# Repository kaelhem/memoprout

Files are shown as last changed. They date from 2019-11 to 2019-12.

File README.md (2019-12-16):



# MemoProut Pad
An open-source Arduino audio game (in french only until now...).

In this repository you will find Arduino source code, sounds and everything necessary to make your own MemoProut Pad!

## Contributing

Contributions in any form are welcome! If you find a bug, please [file an issue.](https://github.com/kaelhem/memoprout/issues)

## License

This project is licensed under the MIT license. See the [LICENSE file](./LICENSE) for more details.

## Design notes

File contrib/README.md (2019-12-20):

# MemoProut Pad - contributions

Vous avez une super idée pour un nouveau mode de jeu  à mettre sur votre MemoProut Pad ? Ce guide vous donne la marche à suivre.

##  Créer de nouveaux sons

Les sons du MemoProut Pad sont encodés en PCM (8bits), et enregistrés dans des fichiers _.wav_.

La méthode la plus simple est d'utiliser [Audacity](https://www.audacityteam.org/) qui est gratuit, open-source et multi-plateforme.

Il y plusieurs étapes à effectuer avec Audacity afin d'encoder chaque son dans un format valide pour votre MemoProut Pad.

1. Ouvrez votre fichier sonore avec Audacity.

2. Sélectionnez tout (dans le menu, cliquez sur _Sélectionner/Tout_)

3. Si le son est en stéréo, le passer en mono (dans le menu, cliquez sur _Pistes/Mix/Mix stéréo vers mono_)

4. Normaliser le volume (dans le menu, cliquez sur _Effets/Normaliser..._) avec les paramètres par défaut (-1.0 dB d'amplitude de crête)

5. Changer la fréquence pour 11025 Hz (sélectionnez 11025 dans la liste déroulante _"Taux du projet"_ en bas à gauche)

6. Mixer le rendu (dans le menu, cliquez sur _Pistes/Mix/Mixage et rendu_)

7. Exporter le son au bon format (dans le menu, cliquez sur _Fichier/Exporter/Exporter l'audio..._) puis sélectionnez ces options :

   + **Type de filtre** : _Autres formats non-compressés_
   + **Entête** : _WAV (Microsoft)_
   + **Encodage** : _Unsigned 8-bits PCM_

## Créer un nouveau mode de jeu

Il existe 2 styles de jeux différents : _"prose"_ où les sons joués forment des phrases, et _"simple"_ où les sons joués s'enchainent sans ordre particulier.

#### Style _prose_

Pour créér un mode de jeu basé sur des phrases, il faut préparer un dossier avec un nom court (6 lettres max.) en majuscules, contenant :

+ 8 sons de _sujets_ (ex. "Donald Trump", "La mouche qui pète", ...) nommés SUBJECT1.wav, SUBJECT2.wav, ... etc jusque SUBJECT8.wav (les majuscules sont importantes).
+ 8 sons d'actions (ex. "se prend pour", "a mangé", ...) nommés VERB1.wav, VERB2.wav, ...etc.
+ 8 sons de _complément_ (ex. "une banane", "une crotte de chien", ...) nommés COMP1.wav, COMP2.wav, ...etc.
+ 4 sons de liaison (ex. "et après", "ensuite", ...) nommés INTER1.wav, INTER2.wav, ...etc.
+ 1 son pour le nom du mode de jeu nommé GAME.wav
+ 1 son pour le _game-over_ nommé LOOSE.wav

#### Style _simple_

Pour créér un mode de jeu basé sur des sons simples, il faut préparer un dossier avec un nom court (6 lettres max.) en majuscules, contenant :

+ 28 sons nommés M1.wav, M2.wav, ...etc. jusque M28.wav (les majuscules sont importantes).

+ 1 son pour le nom du mode de jeu nommé GAME.wav
+ 1 son pour le _game-over_ nommé LOOSE.wav

## Ajouter un mode de jeu sur mon MemoProut Pad

Afin que votre nouveau mode de jeu puisse fonctionner sur votre MemoProut Pad, il faut :

+ copier le dossier précedemment créé à la racine de la carte SD.

+ dans le dossier _GAMES_ de la carte SD, dupliquer le fichier BASIC.PRT (pour le style _"prose"_) ou MUSIC.PRT (pour le style _"simple"_), et le renommer comme le dossier précédemment créé en conservant l'extension _.PRT_. Par exemple si votre dossier se nomme _"MACHIN"_, ce fichier devra être nommé _"MACHIN.PRT"_.

+ à l'aide d'un éditeur de texte, ouvrir le fichier GAMES.PRT se trouvant à la racine de la carte SD et ajouter une ligne contenant le nom de dossier, un espace et un 1 (pour le style _"prose"_) ou un 2 (pour le style _"simple"_).

  >  Par exemple, pour un style de jeu _"prose"_ et un dossier nommé _"MACHIN"_, ajouter cette ligne :

  ```
  MACHIN 1
  ```

  >  Pour un style de jeu _"simple"_ et un dossier nommé _"MACHIN"_, ajouter cette ligne :

  ```
  MACHIN 2
  ```

Et voilà ! Vous pouvez maintenant profiter de votre nouveau mode de jeu personnalisé.

## Comment partager mon mode jeu ?

Pour partager un nouveau mode de jeu, vous pouvez ouvrir une _pull-request_ sur le GitHub du projet en plaçant votre mode de jeu dans le dossier _"contrib"_ de la branche _master_.

Si vous ne savez pas comment faire, le plus simple est encore de m'envoyer un mail avec les sons en pièce jointe sur memoproutpad@gmail.com, et je m'occuperai du reste.

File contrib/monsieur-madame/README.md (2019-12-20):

# MemoProut Pad - monsieur / madame

## C'est quoi ?

Un mode de jeu supplémentaire pour adultes.

## Comment on l'installe ?

1. [Télécharger les sources](https://github.com/kaelhem/memoprout/archive/master.zip)
2. Dé-zipper l'archive et aller dans le dossier _master/contrib/monsieur-madame_
3. Copier le dossier _MRMME_ à la racine de la carte SD.
4. Copier le fichier _MRMME.PRT_ dans le dossier _GAMES_ de la carte SD.
5. Avec un éditeur de texte, éditer le fichier _GAMES.PRT_ de la carte SD pour ajouter cette ligne :

```
MRMME 2
```

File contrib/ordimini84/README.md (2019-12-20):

# MemoProut Pad - ordimini 1984

Nostalgie, nostalgie...

## C'est quoi ?

Un mode de jeu supplémentaire basé sur les sons du memo de l'Ordimini !

> Ces sons ont été récupérés via l'excellent émulateur : [ordimini.net](http://www.ordimini.net)

## Comment on l'installe ?

1. [Télécharger les sources](https://github.com/kaelhem/memoprout/archive/master.zip)
2. Dé-zipper l'archive et aller dans le dossier _master/contrib/ordimini84_
3. Copier le dossier _ORDI_ à la racine de la carte SD.
4. Copier le fichier _ORDI.PRT_ dans le dossier _GAMES_ de la carte SD.
5. Avec un éditeur de texte, éditer le fichier _GAMES.PRT_ de la carte SD pour ajouter cette ligne :

```
ORDI 2
```

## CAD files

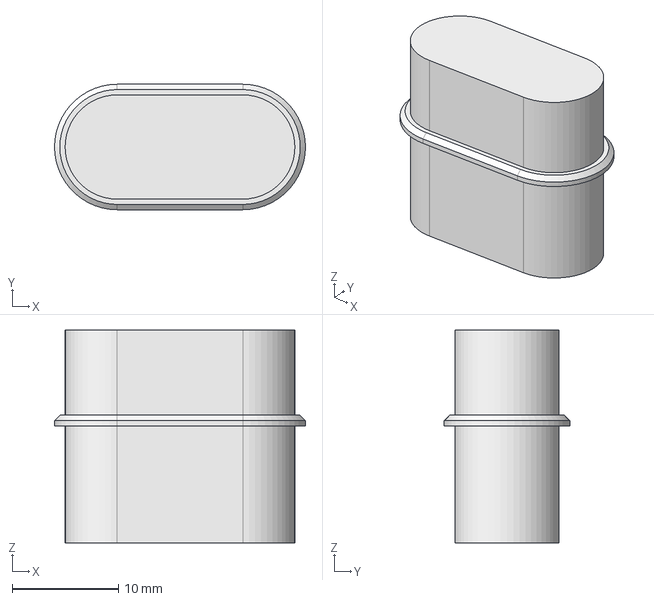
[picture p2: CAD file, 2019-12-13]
make/3dprint/response-led-cap.FCStd
23.6 x 11.8 x 20.0 mm

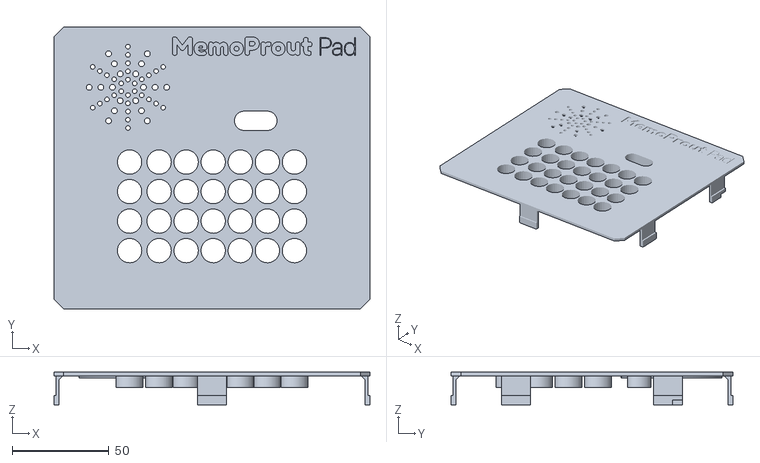
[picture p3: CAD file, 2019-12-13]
make/3dprint/case-front.stl
163.1 x 145.3 x 17.0

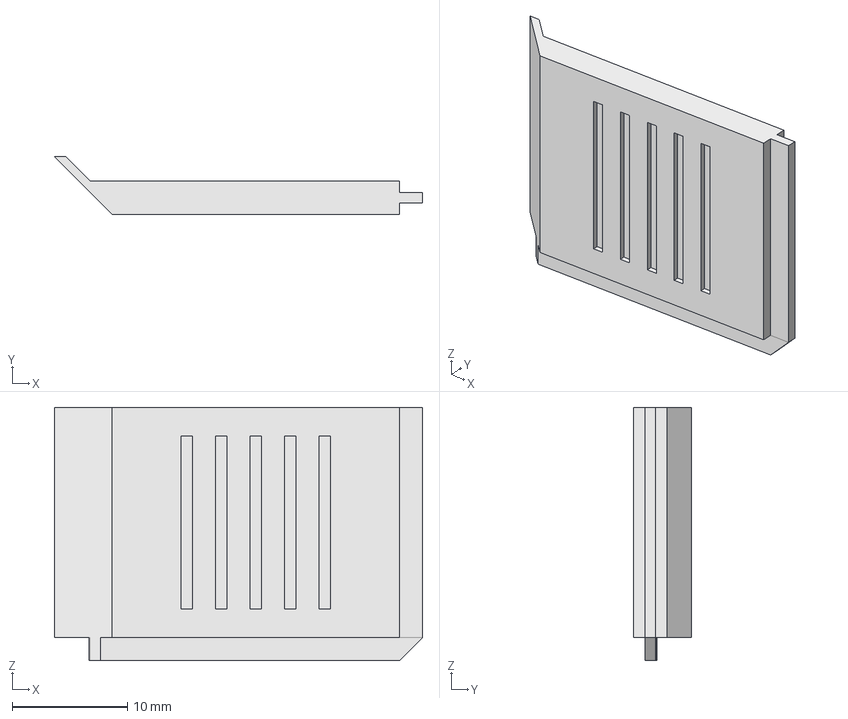
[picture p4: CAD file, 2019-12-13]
make/3dprint/battery-door.FCStd
32.0 x 5.00 x 22.0 mm

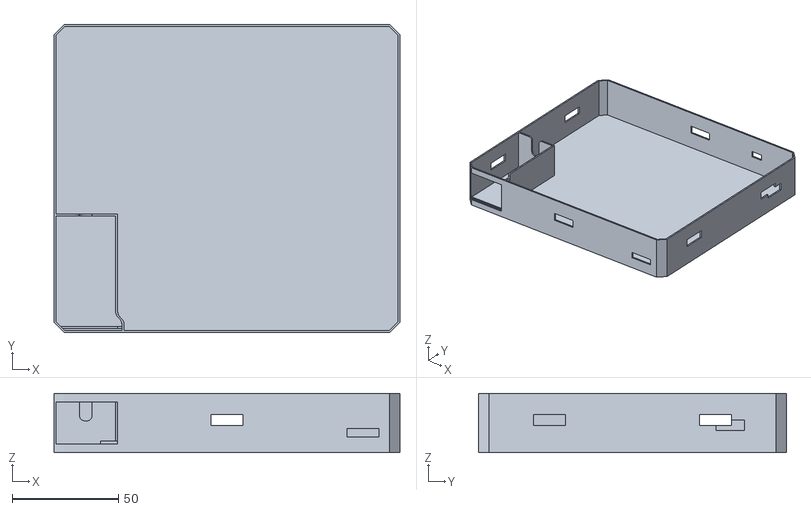
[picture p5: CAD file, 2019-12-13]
make/3dprint/case-back.stl
163.1 x 145.3 x 28.0

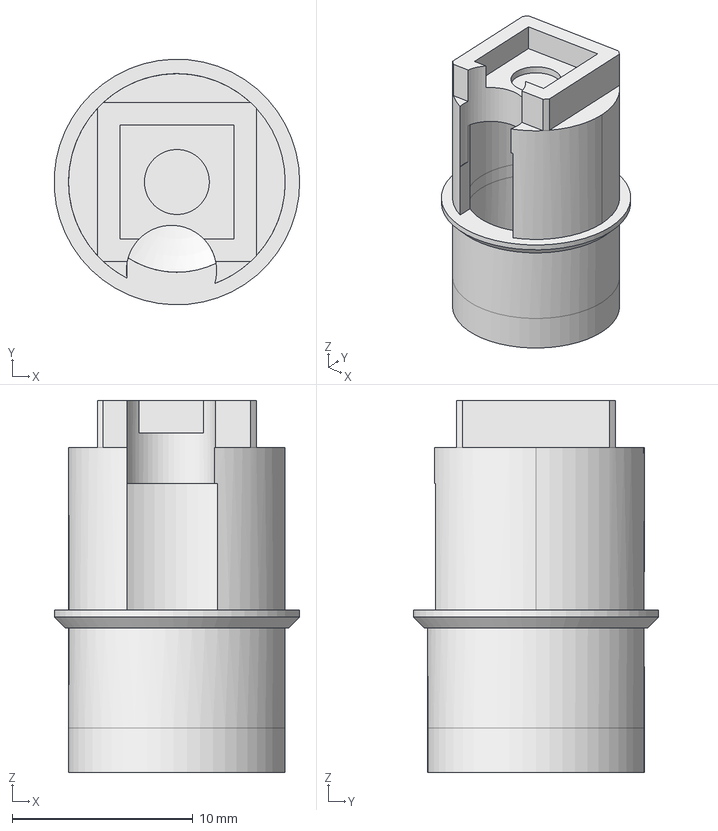
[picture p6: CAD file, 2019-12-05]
make/3dprint/button.FCStd
13.6 x 13.6 x 20.6 mm

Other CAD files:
contrib/monsieur-madame/MRMME.PRT
contrib/ordimini84/ORDI.PRT
data/GAMES.PRT
data/GAMES/BASIC.PRT
data/GAMES/CINEMA.PRT
data/GAMES/KIDS.PRT
data/GAMES/MUSIC.PRT
make/3dprint/battery-door.stl
make/3dprint/button.stl
make/3dprint/response-led-cap.stl

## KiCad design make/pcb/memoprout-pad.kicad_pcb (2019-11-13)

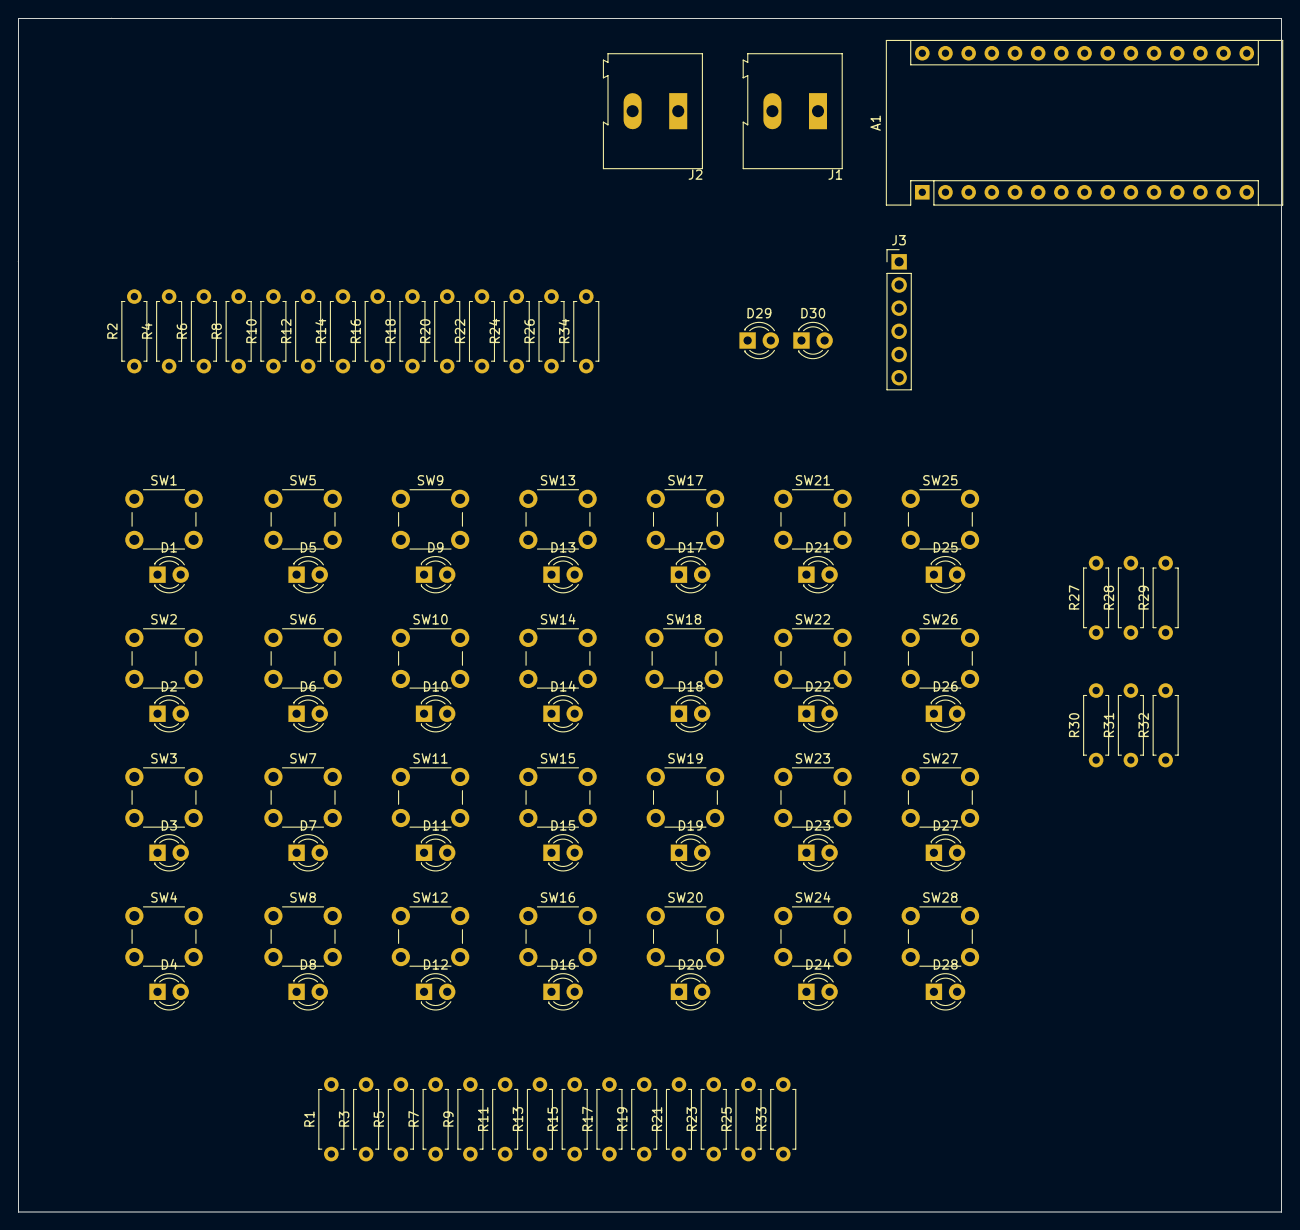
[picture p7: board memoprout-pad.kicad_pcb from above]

Board: 2 copper layers, 138.4 x 130.8 mm, 96 parts (0 on the bottom side), 72 nets, no tracks yet.

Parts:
A1: Arduino_Nano_v3.x; Arduino_Nano
D1, D2, D3, D4, D5, D6, D7, D8, D9, D10, D11, D12, D13, D14, D15, D16, D17, D18, D19, D20, D21, D22, D23, D24, D25, D26, D27, D28, D29, D30: LED; LED_D3.0mm
J1: POWER; TerminalBlock_Altech_AK300-2_P5.00mm
J2: SPEAKER; TerminalBlock_Altech_AK300-2_P5.00mm
J3: SD CARD; PinHeader_1x06_P2.54mm_Vertical
R1, R2: 10KΩ; R_Axial_DIN0207_L6.3mm_D2.5mm_P7.62mm_Horizontal
R3, R4: 3.3KΩ; R_Axial_DIN0207_L6.3mm_D2.5mm_P7.62mm_Horizontal
R5, R6: 1.8KΩ; R_Axial_DIN0207_L6.3mm_D2.5mm_P7.62mm_Horizontal
R7, R8: 1KΩ; R_Axial_DIN0207_L6.3mm_D2.5mm_P7.62mm_Horizontal
R9, R10: 680Ω; R_Axial_DIN0207_L6.3mm_D2.5mm_P7.62mm_Horizontal
R11, R12: 560Ω; R_Axial_DIN0207_L6.3mm_D2.5mm_P7.62mm_Horizontal
R13, R14, R15, R16: 330Ω; R_Axial_DIN0207_L6.3mm_D2.5mm_P7.62mm_Horizontal
R17, R18: 220Ω; R_Axial_DIN0207_L6.3mm_D2.5mm_P7.62mm_Horizontal
R19, R20, R21, R22: 180Ω; R_Axial_DIN0207_L6.3mm_D2.5mm_P7.62mm_Horizontal
R23, R24, R25, R26, R32: 120Ω; R_Axial_DIN0207_L6.3mm_D2.5mm_P7.62mm_Horizontal
R27, R28, R29, R30, R31: R; R_Axial_DIN0207_L6.3mm_D2.5mm_P7.62mm_Horizontal
R33, R34: 1.5KΩ; R_Axial_DIN0207_L6.3mm_D2.5mm_P7.62mm_Horizontal
SW1, SW2, SW3, SW4, SW5, SW6, SW7, SW8, SW9, SW10, SW11, SW12, SW13, SW14, SW15, SW16, SW17, SW18, SW19, SW20, SW21, SW22, SW23, SW24, SW25, SW26, SW27, SW28: BT0; SW_PUSH_6mm_H4.3mm_4Pins

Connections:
+5V: A1.27, J3.2, R33.1, R34.1
/D9: A1.12, J2.2
/GND: A1.4, J1.2, J2.1, J3.1, SW25.4, SW26.4, SW27.4, SW28.4
/VIN: A1.30, J1.1
BT_1: A1.20, R26.1, R34.2, SW25.1
BT_2: R24.1, R26.2, SW21.1
BT_3: R22.1, R24.2, SW17.1
BT_4: R20.1, R22.2, SW13.1
BT_5: R18.1, R20.2, SW9.1
BT_6: R16.1, R18.2, SW5.1
BT_7: R14.1, R16.2, SW1.1
BT_8: R12.1, R14.2, SW26.1
BT_9: R10.1, R12.2, SW22.1
BT_10: R8.1, R10.2, SW18.1
BT_11: R6.1, R8.2, SW14.1
BT_12: R4.1, R6.2, SW10.1
BT_13: R2.1, R4.2, SW6.1
BT_14: R2.2, SW2.1
BT_15: A1.21, R25.1, R33.2, SW27.1
BT_16: R23.1, R25.2, SW23.1
BT_17: R21.1, R23.2, SW19.1
BT_18: R19.1, R21.2, SW15.1
BT_19: R17.1, R19.2, SW11.1
BT_20: R15.1, R17.2, SW7.1
BT_21: R13.1, R15.2, SW3.1
BT_22: R11.1, R13.2, SW28.1
BT_23: R9.1, R11.2, SW24.1
BT_24: R7.1, R9.2, SW20.1
BT_25: R5.1, R7.2, SW16.1
BT_26: R3.1, R5.2, SW12.1
BT_27: R1.1, R3.2, SW8.1
BT_28: R1.2, SW4.1
CS: A1.13, J3.3
LED_1: D3.1, D4.1, D7.2, D8.2, D11.1, D12.1, D15.2, D16.2, D20.1, D24.2, R27.1
LED_2: D2.1, D4.2, D6.2, D8.1, D10.1, D14.2, D19.1, D23.2, D27.1, D28.2, R28.1
LED_3: D1.1, D5.2, D9.1, D12.2, D13.2, D16.1, D18.1, D19.2, D22.2, D23.1, R29.1
LED_4: D17.1, D18.2, D20.2, D21.2, D22.1, D24.1, D25.1, D26.2, D27.2, D28.1, R30.1
LED_5: D1.2, D2.2, D3.2, D5.1, D6.1, D7.1, D17.2, D21.1, D29.2, D30.1, R31.1
LED_6: D9.2, D10.2, D11.2, D13.1, D14.1, D15.1, D25.2, D26.1, D29.1, D30.2, R32.1
MISO: A1.15, J3.5
MOSI: A1.14, J3.4
unnamed: A1.5, R27.2
unnamed: A1.6, R28.2
unnamed: A1.7, R29.2
unnamed: A1.8, R30.2
unnamed: A1.9, R31.2
unnamed: A1.10, R32.2
unnamed: SW1.4, SW5.3
unnamed: SW2.4, SW6.3
unnamed: SW3.4, SW7.3
unnamed: SW4.4, SW8.3
unnamed: SW5.4, SW9.3
unnamed: SW6.4, SW10.3
unnamed: SW10.4, SW14.3
unnamed: SW7.4, SW11.3
unnamed: SW11.4, SW15.3
unnamed: SW8.4, SW12.3
unnamed: SW12.4, SW16.3
unnamed: SW9.4, SW13.3
unnamed: SW13.4, SW17.3
unnamed: SW14.4, SW18.3
unnamed: SW15.4, SW19.3
unnamed: SW16.4, SW20.3
unnamed: SW17.4, SW21.3
unnamed: SW18.4, SW22.3
unnamed: SW19.4, SW23.3
unnamed: SW20.4, SW24.3
unnamed: SW21.4, SW25.3
unnamed: SW22.4, SW26.3
unnamed: SW23.4, SW27.3
unnamed: SW24.4, SW28.3
SCK: A1.16, J3.6

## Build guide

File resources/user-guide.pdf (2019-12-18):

## MemoProut Pad©

# Guide de l’utilisateur

MemoProut Pad© est un jeu audio adapté aux pas trop petits et aux plus grands

# Mise en garde

- Ne pas jeter sur la voie publique
- Ne pas s’assoir dessus
- Ne pas mettre au réfrigérateur ou au congélateur
- Ne pas non plus mettre au four
Les médecins recommandent une utilisation journalière mais pas trop prolongée de MemoProut Pad©.

# Conseils d’utilisation

Cet objet de convoitise unique à la finition exceptionnelle fera de toi la personne la plus appréciée de ton entourage. Pour éviter cela,
nous te conseillons de jouer à MemoProut Pad© exclusivement aux toilettes. Même avec le volume au maximum, personne ne se doutera de rien !

Lorsque j’allume mon MemoProut Pad© l’indicateur de réponse clignote en rouge et un message «NO CONFIG» apparait sur les boutons.
La carte SD ne contient pas les bonnes données. Il faut remettre dessus les données d’origine. Pour récupérer les données, télécharge ce fichier zip : https://github.com/kaelhem/memoprout/archive/master.zip et dézippe-le. Copie ensuite le contenu du repertoire master/data à la racine de la carte SD.

J’ai une mémoire pourrie. Puis-je utiliser MemoProut Pad© comme coussin péteur ?
Oui, bien sûr. Il suffit de placer MemoProut Pad© à côté de ta cible et de l’allumer discrètement. Attention, ne pas le placer sous les fesses de ta cible (voir la section Mise en garde).

Un autre problème ?
Tu peux consulter la FAQ sur le site web : memoproutpad.netlify.com

# Informations

Site web : memoproutpad.netlify.com
Github: https://github.com/kaelhem/memoprout

# Légal

MemoProut Pad© n’est pas une marque réservée. N’importe qui peut l’utiliser comme bon lui semble. D’ailleurs, CacaCucu n’est pas reservée non plus... à bon entendeur !

# Problèmes et solutions

Les sons se jouent au ralenti / ne se jouent plus du tout.
Il est sûrement temps de changer la pile ! Profites-en aussi pour changer de slip.

Ça me dit tout le temps «t’es trop trop nul(le)».
Entraine-toi, persévère et tu seras récompensé(e) !

Lorsque j’allume mon MemoProut Pad© l’indicateur de réponse clignote en rouge et un message «NO SD» apparait sur les boutons.
Vérifie que la carte SD soit correctement mise.

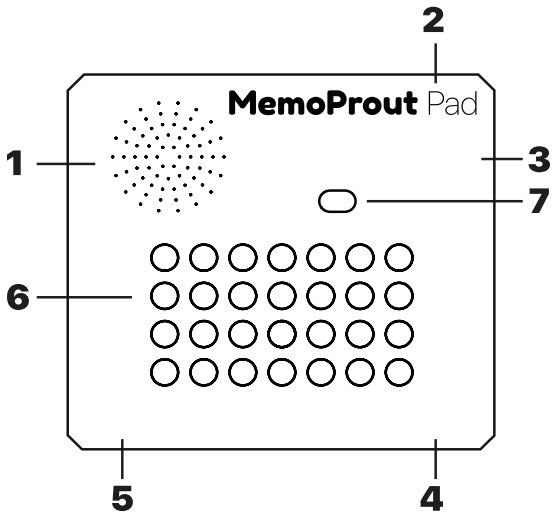
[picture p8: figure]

1. haut-parleur
2. bouton marche/arrêt
3. micro USB
4. lecteur de cartes SD
5. pile 9V
6. boutons
7. indicateur de réponse

# Démarrage

Après avoir mis le bouton marche/arrêt sur ON, MemoProut Pad© affiche le message PROUT et joue le délicat son de démarrage.

# Le jeu

MemoProut Pad© est un jeu de mémorisation.

## Comment jouer ?

Au début de la partie, un son est joué et un bouton est rétro-éclairé. Il faut alors appuyer sur ce bouton. Ensuite, un autre son est joué lié à un autre bouton. Il faut maintenant répéter la séquence complète en repartant du premier bouton. Et ainsi de suite... Chaque nouveau son apporté à la séquence rapporte un point. Le meilleur score est systématiquement enregistré.

# Les contrôles

## Commandes standards

Dans le menu, les boutons correspondants aux commandes standards sont éclairés.
changer le mode de jeu
meilleur score
augmenter le volume
diminuer le volume
commencer une nouvelle partie

Pour vérifier le bon fonctionnement des boutons, appuyer sur . Appuyer sur chaque bouton pour vérifier qu’il s’allume bien. Pour revenir au menu, appuyer sur .

## Commandes cachées

Il existe deux commandes cachées permettant de faire des vérifications sur les leds et les boutons. Pour vérifier les leds, appuyer sur le bouton . Les leds s’allument une à une. Un appui long sur n’importe quel bouton permet de revenir au menu.

## Pendant une partie

Pendant une partie, tu peux effectuer des combinaisons de touches pour effectuer des actions. Il te suffit d’appuyer sur deux boutons en même temps. Les combinaisons possibles sont :
rejouer toute la séquence
quitter la partie et retourner au menu augmenter le volume
diminuer le volume

# Modes de jeu

Il existe 4 modes de jeu différents, ou plus, ou moins, selon les versions.
Classic : Le MemoProut originel, créé en l’an de grâce 2009. C’est par lui que tout à commencé. Dans cette version, les sons joués forment des phrases hallucinées à l’humour parfois douteux.
Kids : Basée sur la version Classic, cette version édulcorée est agréablement vocalisée par les plus beaux enfants du monde.
Cinema : La nostalgie vous tend les bras avec cette version cinema et ses extraits de films en guise de sons. Choisis minutieusement, ces moments cultes sont autant de délicieuses petites madeleines de Prout ! Music : La rock n’ roll attitude façon MemoProut !

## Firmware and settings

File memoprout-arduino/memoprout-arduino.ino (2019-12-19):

/*
  MemoProutPad v1.0 - Created by klem on 06/11/2019
  An open-source Arduino audio game
  https://github.com/kaelhem/memoprout  
*/
#include "memoprout.h"
#include "MemoProut_controller.h"
#include "MemoProut_speaker.h"
#include "MemoProut_pins.h"
#include "MemoProut_calibration.h"
#include <avr/pgmspace.h>

#define APP_MAJOR_VERSION 1
#define APP_MINOR_VERSION 0

#define NO_PRESSED_BUTTON 255

// MAIN STATES
#define STARTUP 0
#define MENU 1
#define GAME_LOOP 2
#define GAME_OVER 3
#define CHECK_LEDS 4
#define CHECK_BUTTONS 5

// GAME STATES
#define PREPARE_GAME 0
#define PLAY_SOUND 1
#define WAIT_BUTTON 2
#define REPLAY_ALL 3

GameObject currentGameObject;
unsigned long lastGameListPos = 0;

byte mainState = STARTUP;
byte gameState = PLAY_SOUND;
byte globalGameIndex = 0;

MemoProut_speaker speaker = MemoProut_speaker();
MemoProut_controller controller = MemoProut_controller();

String serialCommand;

bool isConnected = false;

void setup() {
  Serial.begin(57600);
  while (!Serial) {
    ;
  }
  speaker.init();
  controller.init();
  if (!CalibrationUtils::isCalibrated()) {
    Serial.println(F("NO CALIBRATION !"));
    controller.lightUp(controller.LED_OK);
    // TODO : indicate that calibration is starting with messages for user
    calibrateButtons();
  }
}

void loop() {
  if (Serial.available() > 0) {
    isConnected = true;
    updateMode();
  } else {
    switch(mainState) {
      case STARTUP: startup(); break;
      case MENU: menu(); break;
      case GAME_LOOP: gameLoop(); break;
      case GAME_OVER: gameOver(); break;
      case CHECK_LEDS: checkLeds(); break;
      case CHECK_BUTTONS: checkButtons(); break;
    }
  }
}

/**
 * Allow serial communication with host
 */
void updateMode() {
  speaker.disableSound();
  controller.lightUp(controller.LED_OK);
  while(isConnected) {
    readCommand();
    executeCommand();
  }
}

void readCommand() {
  bool done = false;
  serialCommand = "";
  while (!done) {
    if (Serial.available() > 0) {
      char c = Serial.read();
      if (c!=10 && c!=13) {
        serialCommand += c;
      } else if (serialCommand != "") {
        done = true;
      }
    }
  }
}

/**
 * Execute command received by host on serial
 */
void executeCommand() {
  if (DEBUG_MODE) {
    Serial.println(serialCommand);
  }
  if (serialCommand == F("1")) {
    Serial.println("1");
  } else if (serialCommand == F("MKDIR")) {
    createDirectory();
  } else if (serialCommand == F("UP")) {
    uploadFile();
  } else if (serialCommand == F("CALIB")) {
    calibrateButtons();
  } else if (serialCommand == F("VER")) {
    Serial.print(APP_MAJOR_VERSION);
    Serial.print(F("."));
    Serial.println(APP_MINOR_VERSION);
  } else if (serialCommand == F("LSGAMES")) {
    listGames();
  } else if (serialCommand == F("EXIT")) {
    isConnected = false;
  } else {
    Serial.println(F("command unknown"));
  }
  serialCommand = "";
}

void listGames() {
  File gameListFile = SD.open(F("GAMES.PRT"), FILE_READ);
  if (gameListFile) {
    while (gameListFile.available() > 0) {
      String buffer = gameListFile.readStringUntil(' ');
      Serial.println(buffer);
      gameListFile.readStringUntil('\n');
    }
  } else {
    Serial.println(F("ERR"));
  }
  gameListFile.close();
}

void calibrateButtons() {
  Serial.println(F("Calibration of buttons - it will be store in EEPROM"));
  byte i;
  int pinValue = -1;
  byte countIdenticals;
  int buttons[14];
  for (i = 0; i < 14; ++i) {
    countIdenticals = 0;
    byte btId = controller.getButtonIdAtIndex(i);
    controller.lightUp(btId);
    while(countIdenticals < 3) {
      int readValue = analogRead(i < 14 ? 1 : 2);
      if (readValue == pinValue) {
        ++countIdenticals;
      } else {
        countIdenticals = 0;
        pinValue = readValue < 1000 ? readValue : -1;
      }
    }
    buttons[btId] = pinValue;
    while(pinValue < 1000) {
      pinValue = analogRead(i < 14 ? 1 : 2);
    }
    pinValue = -1;
  }
  CalibrationUtils::saveCalibration(buttons);
  Serial.println(F("Done."));
  controller.init();
}

void createDirectory() {
  readCommand();// get dir name
  char *dirname = serialCommand.c_str();
  if (SD.exists(dirname)) {
    Serial.println(0); // directory already exists
  } else {
    SD.mkdir(dirname);
    Serial.println(1);
  }
}

void uploadFile() {
  readCommand();// get file name
  char *filename = serialCommand.c_str();
  if (SD.exists(filename)) {
    Serial.println(0); // file already exists
  } else {
    File fileToUpload = SD.open(filename, FILE_WRITE);
    Serial.println(1); // wait file size
    readCommand();
    unsigned long len = serialCommand.toInt();
    //byte uploadBuf[255];
    //byte bufferPos = 0;
    unsigned long copied = 0;
    byte chunkSize = 0;
    Serial.println(1); // ready to receive file data
    while (copied < len) {
      if (copied < len && chunkSize < 4096) {
        if (Serial.available() > 0) {
          fileToUpload.write(Serial.read());
          ++copied;
          ++chunkSize;
        }
        /*++chunkSize;
        if (chunkSize == 32) {
          fileToUpload.flush();
          chunkSize = 0;
          //Serial.println(F("CHUNK_OK"));
        }*/
      } else if (chunkSize > 0) {
        fileToUpload.flush();
        chunkSize = 0;
      }
      /*if (bufferPos == 64) {
        fileToUpload.flush();
        bufferPos = 0;
      }*/
    }
    /*
    if (bufferPos > 0) {
      fileToUpload.write(uploadBuf, bufferPos);
    }
    */
    fileToUpload.close();
    Serial.println(F("NEXT"));
  }
}

byte checkLedIndex = 0;

void checkLeds() {
  if (DEBUG_MODE) {
    Serial.println(F("check leds"));
  }
  controller.listenButtons();
  if (controller.currentPressedButton != NO_PRESSED_BUTTON) {
    checkLedIndex = 0;
    gotoState(MENU);
  } else {
    controller.lightUp(controller.getButtonIdAtIndex(checkLedIndex));
    delay(200);
    if (++checkLedIndex == 28) {
      checkLedIndex = 0;
      controller.lightUp(controller.LED_OK);
      delay(200);
      controller.lightUp(controller.LED_KO);
      delay(200);
    }
  }
}

void checkButtons() {
  controller.listenButtons();
  if (controller.currentMultiTouchAction != TOUCH_NONE) {
    gotoState(MENU);
  }
}

String getCurrentGameName() {
  return String(currentGameObject.gameName);
}

void setNextGameObject() {
  File gameListFile = SD.open(F("GAMES.PRT"), FILE_READ);
  if (gameListFile) {
    gameListFile.seek(lastGameListPos);
    String buffer = gameListFile.readStringUntil(' ');
    buffer.trim();
    String kindStr = gameListFile.readStringUntil('\n');
    kindStr.trim();
    byte kind = byte(kindStr.toInt());
    lastGameListPos = gameListFile.position() < gameListFile.size() ? gameListFile.position() : 0;
    gameListFile.close();
    buffer.toCharArray(currentGameObject.gameName, buffer.length() +1);
    currentGameObject.hasSentences = kind == 1;
  } else {
    while (true) {
      controller.blinkLed(controller.LED_KO, 2, 100);
      controller.showMessage(F("NO CONFIG"), 150);
    }
  }
}

void loadConfig() {
  File configFile = SD.open(F("CONFIG.PRT"), FILE_READ);
  if (configFile) {
    globalGameIndex = configFile.read();
    speaker.setVolume(configFile.read());
    configFile.close();
  }
}

void saveConfig() {
  if (SD.exists(F("CONFIG.PRT"))) {
    SD.remove(F("CONFIG.PRT"));
  }
  File configFile = SD.open(F("CONFIG.PRT"), FILE_WRITE);
  configFile.write(globalGameIndex);
  configFile.write(speaker.getVolume());
  configFile.close();
}

void updateGlobalGameIndex() {
  ++globalGameIndex;
  saveConfig();
}

void startup() {
  if (!speaker.isReady()) {
    controller.blinkLed(controller.LED_KO, 3, 100);
    controller.showMessage(F("NO SD"), 150);
  } else {
    loadConfig();
    controller.blinkLed(controller.LED_OK, 1, 100);
    unsigned int i = 0;
    Serial.println(F("STARTUP"));
    // lets board have time to read potential serial entry (~100ms)
    while (i < 50000 && Serial.available() == 0) {
      ++i;
    }
    if (Serial.available() == 0) {
      setNextGameObject();
      speaker.playSound(F("PROUTS/P9.WAV"));
      controller.showMessage(F("PROUT"), 100);
      speaker.stopSound();
      controller.resetLeds();
      mainState = MENU;
      speaker.playSoundAndWait(getCurrentGameName() + F("/GAME.WAV"));
    }
  }
}

void gotoState(byte state) {
  // WAIT
  mainState = 255;
  while (controller.currentPressedButton != NO_PRESSED_BUTTON) {
    controller.listenButtons();
  }
  if (state == MENU) {
    speaker.playSoundAndWait(F("UI/MENU.WAV"));
  }
  mainState = state;
}

void switchGameKind() {
  setNextGameObject();
  speaker.playSoundAndWait(getCurrentGameName() + F("/GAME.WAV"));
}

void upVolume() {
  if (speaker.canUpVolume && !speaker.isPlaying()) {
    speaker.upVolume();
    saveConfig();
    speaker.playSoundAndWait(F("PROUTS/P10.WAV"));    
  }
}

void downVolume() {
  if (speaker.canDownVolume && !speaker.isPlaying()) {
    speaker.downVolume();
    saveConfig();
    speaker.playSoundAndWait(F("PROUTS/P10.WAV"));
  }
}

void showHiScore() {
  if (!speaker.isPlaying()) {
    byte scoreSoundIndex = max(0, min(readHiScore(), 10));
    if (scoreSoundIndex > 0) {
      speaker.playSoundAndWait(F("UI/HISCORE.WAV"));
    }
    speaker.playSoundAndWait("SCORE/S" + String(scoreSoundIndex) + F(".WAV"));
  } 
}

void menu() {
  controller.listenButtons();
  switch (controller.currentPressedButton) {
    case BT_1: switchGameKind(); break;
    case BT_22: showHiScore(); break;
    case BT_7: upVolume(); break;
    case BT_14: downVolume(); break;
    case BT_28:
      gameState = PREPARE_GAME;
      gotoState(GAME_LOOP);
    break;

    // hidden features :
    case BT_11:
      gotoState(CHECK_LEDS);
    break;
    case BT_18:
      gotoState(CHECK_BUTTONS);
    break;
  }
  byte ledsToEnlight[] = { BT_1, BT_22, BT_7, BT_14, BT_28 };
  const byte numLeds = sizeof(ledsToEnlight) / sizeof(byte);
  controller.multiLightUp(ledsToEnlight, numLeds);
}

byte waitButtonRelease = NO_PRESSED_BUTTON;
GameSound firstWaitSound;
GameSound *currentWaitSound;
byte currentWaitButtonIndex;
byte score;

void prepareNewGame() {
  controller.resetLeds();
  score = 0;
  currentWaitButtonIndex = 0;

  byte i;

  // read the next game ref (pre-registered random values)
  byte randomGame[84];
  File refGameFile = SD.open("GAMES/" + getCurrentGameName() + F(".PRT"), FILE_READ);
  refGameFile.seek(84 * globalGameIndex);
  for (i = 0; i < 84; ++i) {
    randomGame[i] = refGameFile.read();
  }
  refGameFile.close();

  // write this game in buffer file
  if (SD.exists(F("TMP.PRT"))) {
    SD.remove(F("TMP.PRT"));
  }
  File gameFile = SD.open(F("TMP.PRT"), FILE_WRITE);
  for (i = 0; i < 84; ++i) {
    gameFile.write(randomGame[i]);
  }
  gameFile.close();
  firstWaitSound = {randomGame[0], randomGame[1], randomGame[2]};
  updateGlobalGameIndex();
  gameState = PLAY_SOUND;
}

GameSound getGameSoundAt(byte index) {
  delay(10);
  File gameFile = SD.open(F("TMP.PRT"), FILE_READ);
  gameFile.seek(index * 3);
  GameSound gameSound = {};
  gameSound.kind = gameFile.read();
  gameSound.variant = gameFile.read();
  gameSound.buttonId = gameFile.read();
  gameFile.close();
  if (DEBUG_MODE) {
    Serial.println("read " + String(index) + ": " + String(gameSound.kind) + ", " + String(gameSound.variant) + ", " + String(gameSound.buttonId));
  }
  return gameSound;
}

byte readHiScore() {
  File scoreFile = SD.open(F("SCORE.PRT"), FILE_READ);
  if (scoreFile) {
    byte readScore = scoreFile.read();
    scoreFile.close();
    return readScore;
  }
  return 0;
}

void writeHiScore(byte newScore) {
  if (SD.exists(F("SCORE.PRT"))) {
    SD.remove(F("SCORE.PRT"));
  }
  File scoreFile = SD.open(F("SCORE.PRT"), FILE_WRITE);
  scoreFile.write(newScore);
  scoreFile.close();
}

void gameLoop() {
  switch (gameState) {
    case PREPARE_GAME:
      prepareNewGame();
    break;
    case PLAY_SOUND:
      if (!speaker.isPlaying()) {
        GameSound gameSound = getGameSoundAt(score);
        controller.lightUp(gameSound.buttonId);
        currentWaitButtonIndex = 0;
        currentWaitSound = &firstWaitSound;
        waitButtonRelease = NO_PRESSED_BUTTON;
        speaker.playSoundAndWait(getFilename(gameSound.kind, gameSound.variant));
        controller.resetLeds();
        gameState = WAIT_BUTTON;
      }
    break;
    case REPLAY_ALL:
      for (byte i = 0; i <= score; ++i) {
        GameSound gameSound = getGameSoundAt(i);
        controller.lightUp(gameSound.buttonId);
        speaker.playSoundAndWait(getFilename(gameSound.kind, gameSound.variant));
        controller.resetLeds();
        currentWaitButtonIndex = 0;
        currentWaitSound = &firstWaitSound;
        waitButtonRelease = NO_PRESSED_BUTTON;
        gameState = WAIT_BUTTON;
      }
    break;
    case WAIT_BUTTON:
      controller.listenButtons();
      if (controller.currentPressedButton != NO_PRESSED_BUTTON) {
        if (controller.currentMultiTouchAction != TOUCH_NONE) {
          byte action = controller.currentMultiTouchAction;
          while (controller.currentPressedButton != NO_PRESSED_BUTTON) {
            controller.listenButtons();
          }
          waitButtonRelease = NO_PRESSED_BUTTON;
          switch (action) {
            case TOUCH_1: gotoState(MENU); break;
            case TOUCH_2: gameState = REPLAY_ALL; break;
            case TOUCH_3: upVolume(); break;
            case TOUCH_4: downVolume(); break;
          }
        } else {
          waitButtonRelease = controller.currentPressedButton;
        }
      } else if (waitButtonRelease != NO_PRESSED_BUTTON) {
        if (waitButtonRelease == currentWaitSound->buttonId) {
          waitButtonRelease = NO_PRESSED_BUTTON;
          byte ledsToEnlight[] = { controller.LED_OK, currentWaitSound->buttonId };
          for (byte lightTimer = 0; lightTimer < 100; ++lightTimer) {
            controller.multiLightUp(ledsToEnlight, 2); 
          }
          controller.lightUp(currentWaitSound->buttonId);
          speaker.playSound(getFilename(currentWaitSound->kind, currentWaitSound->variant));
          while(speaker.isPlaying()) {
            if (currentWaitButtonIndex <= score) {
              controller.listenButtons();
              if (controller.currentPressedButton != NO_PRESSED_BUTTON) {
                speaker.stopSound();
                waitButtonRelease = controller.currentPressedButton;
              }
            } else {
              delay(1);
            }
          }
          controller.resetLeds();
          if (++currentWaitButtonIndex <= score) {
            currentWaitSound = &getGameSoundAt(currentWaitButtonIndex);
          } else {
            score += 1;
            gameState = PLAY_SOUND;
          }
        } else {
          gotoState(GAME_OVER);
        }
      }
    break;
  }  
}

void gameOver() {
  byte hiScore = readHiScore();
  if (score > hiScore) {
    writeHiScore(score);
  }
  controller.blinkLed(controller.LED_KO, 3, 100);
  speaker.playSoundAndWait(F("UI/LOOSE.WAV"));
  if (score > 0) {
    speaker.playSoundAndWait(F("UI/URSCORE.WAV"));
    byte scoreSoundIndex = max(0, min(score, 10));
    speaker.playSoundAndWait("SCORE/S" + String(scoreSoundIndex) + F(".WAV"));
  }
  if (score < 5) {
    speaker.playSound(getCurrentGameName() + F("/LOOSE.WAV"));
  }
  controller.showMessage(F("YOU LOOSE"), 160);
  while (speaker.isPlaying()) {
    delay(1);
  }
  gotoState(MENU);
}

String getFilename(byte soundKindIndex, byte soundVariantIndex) {
  if (currentGameObject.hasSentences) {
    char *sndId[] = {
      "SUBJECT",
      "VERB",
      "COMP",
      "INTER"
    };
    return getCurrentGameName() + "/" + String(sndId[soundKindIndex]) + String(soundVariantIndex) + F(".WAV"); 
  } else {
    return getCurrentGameName() + "/M" + String(soundVariantIndex) + F(".WAV");
  }
}

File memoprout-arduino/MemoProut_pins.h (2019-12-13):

/*
  MemoProut_pins.h - Defines the pins for the Memoprout Pad©
  Created by klem on 06/11/2019
*/
#ifndef MemoProut_pins_h
#define MemoProut_pins_h

// PINS FOR LEDS (charlieplexing)
#define LED_1 2
#define LED_2 3
#define LED_3 4
#define LED_4 5
#define LED_5 6
#define LED_6 7

// PINS (analog) FOR ForteenButtons connectors
#define PIN_BUTTONS_TOP 1
#define PIN_BUTTONS_BOTTOM 2

// PIN for SD card
#define SD_PIN 10

// PIN for speaker
#define SPEAKER_PIN 9


// Buttons identifier
#define BT_1 6
#define BT_2 4
#define BT_3 5
#define BT_4 3
#define BT_5 2
#define BT_6 1
#define BT_7 0
#define BT_8 13
#define BT_9 12
#define BT_10 11
#define BT_11 10
#define BT_12 9
#define BT_13 8
#define BT_14 7
#define BT_15 20
#define BT_16 18
#define BT_17 19
#define BT_18 17
#define BT_19 16
#define BT_20 15
#define BT_21 14
#define BT_22 27
#define BT_23 26
#define BT_24 25
#define BT_25 24
#define BT_26 23
#define BT_27 22
#define BT_28 21

#endif

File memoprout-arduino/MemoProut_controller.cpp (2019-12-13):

/*
  MemoProut_controller.cpp - Library that manage the 28 buttons and the 30 leds of the MemoProut Pad©
  Created by klem on 06/11/2019
*/

#include "Arduino.h"
#include "MemoProut_controller.h"
#include "MemoProut_pins.h"
#include "MemoProut_ledButton.h"
#include "MemoProut_calibration.h"

#include <avr/pgmspace.h>

/*
REFERENCE MAP :
  { {LED_4, LED_6,  BT_1}, {LED_5, LED_4,  BT_2}, {LED_4, LED_5,  BT_3}, {LED_6, LED_3,  BT_4}, {LED_3, LED_6,  BT_5}, {LED_5, LED_3,  BT_6}, {LED_3, LED_5,  BT_7} },
  { {LED_6, LED_4,  BT_8}, {LED_4, LED_3,  BT_9}, {LED_3, LED_4, BT_10}, {LED_6, LED_2, BT_11}, {LED_2, LED_6, BT_12}, {LED_5, LED_2, BT_13}, {LED_2, LED_5, BT_14} },
  { {LED_2, LED_4, BT_15}, {LED_3, LED_2, BT_16}, {LED_2, LED_3, BT_17}, {LED_6, LED_1, BT_18}, {LED_1, LED_6, BT_19}, {LED_5, LED_1, BT_20}, {LED_1, LED_5, BT_21} },
  { {LED_4, LED_2, BT_22}, {LED_4, LED_1, BT_23}, {LED_1, LED_4, BT_24}, {LED_3, LED_1, BT_25}, {LED_1, LED_3, BT_26}, {LED_2, LED_1, BT_27}, {LED_1, LED_2, BT_28} } 
*/

MemoProut_controller::MemoProut_controller()
{
  for (byte i = 0; i < 4; ++ i) {
    for (byte j = 0; j < 7; ++ j) {
      leds[i][j] = MemoProut_ledButton::MemoProut_ledButton();
    }
  }
  
  // row 1
  leds[0][0].init(LED_5, LED_3, BT_1); // BT_1
  leds[0][1].init(LED_3, LED_5, BT_2); // BT_2
  leds[0][2].init(LED_6, LED_3, BT_3); // BT_3
  leds[0][3].init(LED_3, LED_6, BT_4); // BT_4
  leds[0][4].init(LED_5, LED_4, BT_5); // BT_5
  leds[0][5].init(LED_4, LED_5, BT_6); // BT_6
  leds[0][6].init(LED_6, LED_4, BT_7); // BT_7
  // row 2
  leds[1][0].init(LED_5, LED_2, BT_8); // BT_8
  leds[1][1].init(LED_2, LED_5, BT_9); // BT_9
  leds[1][2].init(LED_6, LED_2, BT_10); // BT_10
  leds[1][3].init(LED_2, LED_6, BT_11); // BT_11
  leds[1][4].init(LED_4, LED_3, BT_12); // BT_12
  leds[1][5].init(LED_3, LED_4, BT_13); // BT_13
  leds[1][6].init(LED_4, LED_6, BT_14); // BT_14
  // row 3
  leds[2][0].init(LED_5, LED_1, BT_15); // BT_15
  leds[2][1].init(LED_1, LED_5, BT_16); // BT_16
  leds[2][2].init(LED_6, LED_1, BT_17); // BT_17
  leds[2][3].init(LED_1, LED_6, BT_18); // BT_18
  leds[2][4].init(LED_3, LED_2, BT_19); // BT_19
  leds[2][5].init(LED_2, LED_3, BT_20); // BT_20
  leds[2][6].init(LED_4, LED_2, BT_21); // BT_21
  // row 4
  leds[3][0].init(LED_2, LED_1, BT_22); // BT_22
  leds[3][1].init(LED_1, LED_2, BT_23); // BT_23
  leds[3][2].init(LED_3, LED_1, BT_24); // BT_24
  leds[3][3].init(LED_1, LED_3, BT_25); // BT_25
  leds[3][4].init(LED_4, LED_1, BT_26); // BT_26
  leds[3][5].init(LED_1, LED_4, BT_27); // BT_27
  leds[3][6].init(LED_2, LED_4, BT_28); // BT_28
  
  // init buttonsMap()
  for (byte i = 0; i < 4; ++ i) {
    for (byte j = 0; j < 7; ++ j) {
      byte btId = leds[i][j].getButtonId();
      buttonsMap[btId][0] = leds[i][j].getLedPin0();
      buttonsMap[btId][1] = leds[i][j].getLedPin1();
    }
  }

  buttonsMap[28][0] = LED_5;
  buttonsMap[28][1] = LED_6;
  buttonsMap[29][0] = LED_6;
  buttonsMap[29][1] = LED_5;
  
  LED_OK = 28;
  LED_KO = 29;

  currentPressedButton = 255;
  topButtons = MemoProut_buttons();
  bottomButtons = MemoProut_buttons();
}

byte MemoProut_controller::getButtonIdAt(byte row, byte col)
{
  return leds[row][col].getButtonId();
}

byte MemoProut_controller::getButtonIdAtIndex(byte index)
{
  return getButtonIdAt(floor(index / 7), index % 7);
}

void MemoProut_controller::init()
{
  CalibrationObject calibration = CalibrationUtils::loadCalibration();
  topButtons.init(PIN_BUTTONS_TOP, calibration);
  bottomButtons.init(PIN_BUTTONS_BOTTOM, calibration);
  resetLeds();
}

void MemoProut_controller::lightUp(byte buttonId)
{
   resetLeds();
   pinMode(buttonsMap[buttonId][0], OUTPUT);
   pinMode(buttonsMap[buttonId][1], OUTPUT);
   digitalWrite(buttonsMap[buttonId][0], HIGH);
   digitalWrite(buttonsMap[buttonId][1],LOW);
}

void MemoProut_controller::multiLightUp(byte ledsToEnlight[], byte numLeds)
{
  for (byte i = 0; i < numLeds; ++i) {
    lightUp(ledsToEnlight[i]);
    delay(1);
  }
}

void MemoProut_controller::lightUpColumn(byte pattern, byte column)
{  
  for (byte i = 0; i < 4; ++i) {
    if (bitRead(pattern, i) == 1) {
      lightUp(leds[i][column].getButtonId());
      delay(1);
    }
  }
}

void MemoProut_controller::lightUpPanel(byte patterns[])
{
  for (byte i = 0; i < 7; ++i) {
    lightUpColumn(patterns[i], i);
  }
}

void MemoProut_controller::blinkLed(byte ledIndex, byte numBlink, uint8_t duration)
{
  for (byte i = 0; i < numBlink; ++i) {
    lightUp(ledIndex);
    delay(duration);
    resetLeds();
    delay(duration);
  }
}

String MemoProut_controller::charToLeds(char c) {
  String result;
  switch(c) {
    case 'A': result = F("F5F"); break;
    case 'B': result = F("FC"); break;
    case 'C': result = F("F99"); break;
    case 'D': result = F("F96"); break;
    case 'E': result = F("FBB"); break;
    case 'F': result = F("F51"); break;
    case 'G': result = F("FDD"); break;
    case 'H': result = F("F6F"); break;
    case 'I': result = F("F"); break;
    case 'J': result = F("9F1"); break;
    case 'K': result = F("F2D"); break;
    case 'L': result = F("F8"); break;
    case 'M': result = F("F242F"); break;
    case 'N': result = F("F24F"); break;
    case 'O': result = F("F9F"); break;
    case 'P': result = F("F33"); break;
    case 'Q': result = F("F978"); break;
    case 'R': result = F("F7B"); break;
    case 'S': result = F("BD"); break;
    case 'T': result = F("1F1"); break;
    case 'U': result = F("F8F"); break;
    case 'V': result = F("787"); break;
    case 'W': result = F("78687"); break;
    case 'X': result = F("9669"); break;
    case 'Y': result = F("3C3"); break;
    case 'Z': result = F("9DB9"); break;
    default:
      result = '0';
  }
  return result;
}

void MemoProut_controller::resetLeds()
{
   pinMode(LED_1, INPUT);
   pinMode(LED_2, INPUT);
   pinMode(LED_3, INPUT);
   pinMode(LED_4, INPUT);
   pinMode(LED_5, INPUT);
   pinMode(LED_6, INPUT);
   digitalWrite(LED_1, LOW);
   digitalWrite(LED_2, LOW);
   digitalWrite(LED_3, LOW);
   digitalWrite(LED_4, LOW);
   digitalWrite(LED_5, LOW);
   digitalWrite(LED_6, LOW);
}

// --- BUTTONS ---
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

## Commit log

2019-11-13 added kicad files, sd card data and generator tool
    [BASIC.PRT, CINEMA.PRT, KIDS.PRT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]
2019-11-13 fixed game generator + normalize all sounds + added volume in config file
    [BASIC.PRT, CINEMA.PRT, KIDS.PRT]
2019-11-15 allow to play smoothly by skipping current playing sound
    [memoprout.ino]
2019-11-21 optimisations, clean repo, added ordimini contrib
    [BASIC.PRT, CINEMA.PRT, GAMES.PRT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]
2019-11-21 added user-guide in pdf + renamed things
    [button.FCStd, button.stl, memoprout-pad.kicad_pcb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]
2019-12-03 update arduino code to match pcb scheme + wip on memoprout-connect
2019-12-05 updated stl button model
    [button.FCStd, button.stl]
2019-12-13 added 3D models + updated firmware
    [battery-door.FCStd, battery-door.stl, case-back.stl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]
2019-12-16 added new game mode + fixed some sounds
    [MRMME.PRT]
